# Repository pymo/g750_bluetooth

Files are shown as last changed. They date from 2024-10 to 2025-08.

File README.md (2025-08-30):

# HP Compaq IPAQ G750 Keyboard Bluetooth Adapter

Demo of G750 keyboard

This project makes a Bluetooth adapter for the G750 foldable keyboard. This keyboard was meant to use with vintage PDAs (Windows CE, Palm, Clie etc.). It was sold under various brands (HP, Compaq, Dell, Treo etc.) and has multiple model numbers (G750, G7L0, G7L1, etc.). But as long as they have the same look, this adapter should work for them.

The G750 keyboard uses an distinctive folding mechanism that slides out to both sides, while the middle piece raises up to the same level. A connector is prop’ed up to provide connectivity to the PDA. This project achieved Bluetooth functionality by replacing that connector module with a custom designed Bluetooth module. The Bluetooth module supports BLE 5.3, can pair up to 4 hosts simultaneously, and supports wired USB connection.

Note that there are two variants of the electrical characteristics: G750 uses inverted-TTL for its RX line, while G7L0, G7L1 uses TTL level. Some keyboards also have one or two extra keys depending on the layout and the PDA's OS. See the [protocol analysis and keycodes](g750_protocol.md) for details. Therefore, the hardware wiring and the firmware are slightly different for different models.

There is one exception: G700 for Toshiba, it uses USB protocol instead of serial, so it can not be supported. (There is also a G700 for Palm and Sony Clie, maybe that can be supported, but I haven't tested it yet.)

Support status
-----------

| Brand | Model | Supported | logic level |
| :---: | :---: | :---: | :---: |
| HP | G750 | Yes | inverted TTL |
| Compaq | 249711-001 | Yes | inverted TTL |
| ViewSonic | PPC-KYB-001 | Yes | inverted TTL |
| Dell | G7L0 or G7L1 | Yes | TTL |
| Treo | G740 | Yes | TTL |
| Belkin | G700 for Toshiba | No | USB protocol |
| Belkin | G700 for Palm/Clie | ? | unknown protocol, 5 wires |

Where to buy
-----------

The keyboard itself can be found on eBay for around $20. You can search using the keywords "G750", "249711-001", "G7L0" or "G7L1" + "Keyboard". G740 for Treo has a weird key layout, but if you are willing to swap keycaps, it's also a viable choice.

I have some modded keyboards for sale on [https://www.ebay.com/itm/226948142510](eBay).

If you want the adapter, I've made some for sale at Tindie. [https://www.tindie.com/products/36279/](https://www.tindie.com/products/36279/)

G750 protocol analysis
-----------

[Protocol analysis and keycodes](g750_protocol.md)

Instruction to make the adapter
-----------

[Tutorial for making the adapter](how_to_make.md)

Instruction to install the adapter
-----------

[Tutorial for installing the adapter into the keyboard](install.md)

PCB design and firmware
-----------
These are in a [separate repo](https://github.com/pymo/wch_micro_kbd/), the PCB design is shared with the Palm Portable Keyboard Bluetooth mod. The PCB uses a WCH CH582F chip, a RISC-V based Bluetooth controller. It is low cost, power efficient and easy enough to use, which is why I chose it.

Spacebar Issue Fix
-----------
It is a known issue that these keyboard's spacebar can't reliably register. But [there is a simple fix for that](spacebar_fix.md).

Demo on Youtube
-----------

G750 Keyboard demo (https://www.youtube.com/watch?v=a8__Df5YKs4 "Converting the G750 folding keyboard into Bluetooth")

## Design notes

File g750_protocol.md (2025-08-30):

# G750 protocol analysis

The G750 keyboard and its variants use a three-wire serial protocol. After disassembling the connector module, you can see a JST 3-pin, 1.25mm pitch male header. The 3 wires are:

- Ground

- RXD (Serial data)
  - For G750, the voltage is RS232 level (or more precisely, invert-TTL level, where 0V is 1 and 3.3V is 0)
  - For G740, G7L0 and G7L1, the voltage is TTL level (0V is 0 and 3.3V is 1)

- VCC, I tested with 3.3v and it works.

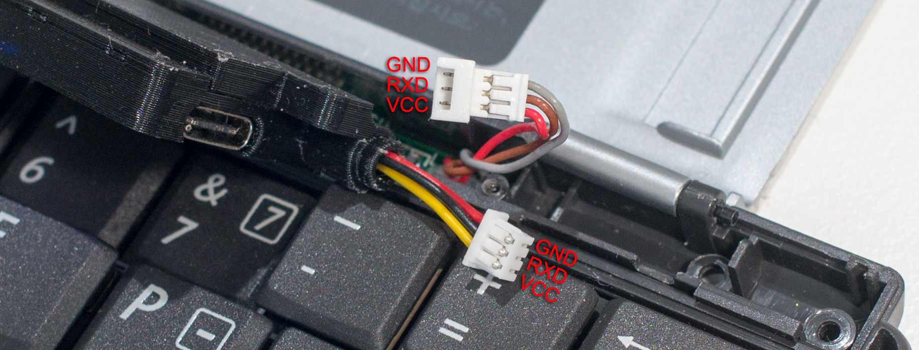
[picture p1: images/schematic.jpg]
Schematic


After the keyboard is supplied with VCC, when a key is pressed or released, it sends a 2-byte key-code over the serial wire. The baud rate is 4800n1. Let’s denote the two bytes as Byte1 and Byte2:

 - The most significant bit of Byte1 denotes the state of the key: 0 is pressed, 1 is released

 - The remaining 7-bit of Byte1 is the scancode, see the following table for the mapping

 - Byte2 is the inversion of Byte1’s 7-bit scancode. i.e. Byte1 & 0b01111111 == ~Byte2. I think it is for error detection. In practice we can ignore this byte and only look at the scancode in Byte1.

Scancode table
----------

G750 with US layout:

| Scan code | HID code | Scan code | HID code | Scan code | HID code | Scan code | HID code |
| :---: | :---: | :---: | :---: | :---: | :---: | :---: | :---: |
| 0x02 | HID_KEY_FN | 0x28 | HID_KEY_ARROW_UP | 0x43 | HID_KEY_I | 0x60 | HID_KEY_ARROW_DOWN |
| 0x07 | HID_KEY_GUI_LEFT | 0x2A | HID_KEY_V | 0x44 | HID_KEY_O | 0x66 | HID_KEY_DELETE |
| 0x0D | HID_KEY_TAB | 0x2B | HID_KEY_F | 0x45 | HID_KEY_0 | 0x70 | "Today" key |
| 0x0E | HID_KEY_GRAVE | 0x2C | HID_KEY_T | 0x46 | HID_KEY_9 | 0x71 | HID_KEY_BACKSPACE |
| 0x11 | HID_KEY_ALT_RIGHT | 0x2D | HID_KEY_R | 0x49 | HID_KEY_PERIOD | 0x73 | HID_KEY_CONTROL_RIGHT |
| 0x12 | HID_KEY_SHIFT_LEFT | 0x2E | HID_KEY_5 | 0x4A | HID_KEY_SLASH |  | |
| 0x14 | HID_KEY_CONTROL_LEFT | 0x2F | HID_KEY_ARROW_RIGHT | 0x4B | HID_KEY_L |  | | 
| 0x15 | HID_KEY_Q | 0x31 | HID_KEY_N | 0x4C | HID_KEY_SEMICOLON |  | |
| 0x16 | HID_KEY_1 | 0x32 | HID_KEY_B | 0x4D | HID_KEY_P |  | |
| 0x1A | HID_KEY_Z | 0x33 | HID_KEY_H | 0x4E | HID_KEY_MINUS |  | | 
| 0x1B | HID_KEY_S | 0x34 | HID_KEY_G | 0x52 | HID_KEY_APOSTROPHE |  | | 
| 0x1C | HID_KEY_A | 0x35 | HID_KEY_Y | 0x54 | HID_KEY_BRACKET_LEFT | | | 
| 0x1D | HID_KEY_W | 0x36 | HID_KEY_6 | 0x55 | HID_KEY_EQUAL |  | |
| 0x1E | HID_KEY_2 | 0x3A | HID_KEY_M | 0x58 | HID_KEY_CAPS_LOCK | | | 
| 0x21 | HID_KEY_C | 0x3B | HID_KEY_J | 0x59 | HID_KEY_SHIFT_RIGHT | | | 
| 0x22 | HID_KEY_X | 0x3C | HID_KEY_U | 0x5A | HID_KEY_RETURN |  | |
| 0x23 | HID_KEY_D | 0x3D | HID_KEY_7 | 0x5B | HID_KEY_BRACKET_RIGHT | | | 
| 0x24 | HID_KEY_E | 0x3E | HID_KEY_8 | 0x5C | HID_KEY_SPACE |  | |
| 0x25 | HID_KEY_4 | 0x41 | HID_KEY_COMMA | 0x5D | HID_KEY_BACKSLASH | | | 
| 0x26 | HID_KEY_3 | 0x42 | HID_KEY_K | 0x5E | HID_KEY_ARROW_LEFT | | | 

G750 with European (UK, ES etc.) layout, mostly the same with US but with the following difference:

| Scan code | HID code |
| :---: | :---: |
| 0x52 | (on the top of the up-arrow key), HID_KEY_EUROPE_1 |
| 0x74 | (to the right of the left-shift key), HID_KEY_EUROPE_2 |

G740 for Treo and G7L1 for Dell, the bottom row has one extra key to the left of the Space key:

| Scan code | G740 Key | G7L1 Key |
| :---: | :---: | :---: |
| 0x02 | Fn | Fn |
| 0x14 | Ctrl | Ctrl |
| 0x07 | opt | Windows |
| 0x70 | find |Today |
| 0x7a | Alt | Home |
| 0x5C | Space | Space |
| 0x11 | Home | alt |
| 0x73 | Menu | ctrl |
| 0x66 | Center | del |
| 0x5E | Left Arrow | Left Arrow |
| 0x60 | Right Arrow | Down Arrow |
| 0x2F | Down Arrow | Right Arrow |

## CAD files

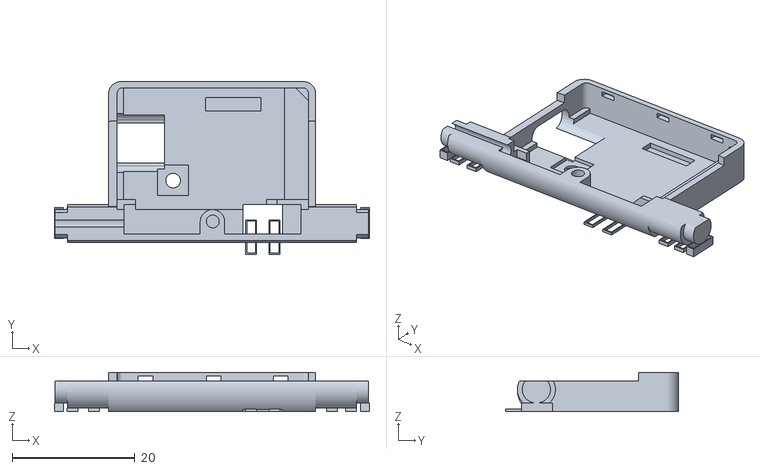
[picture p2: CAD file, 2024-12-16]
3d_print/base.stl
51.2 x 28.1 x 6.40

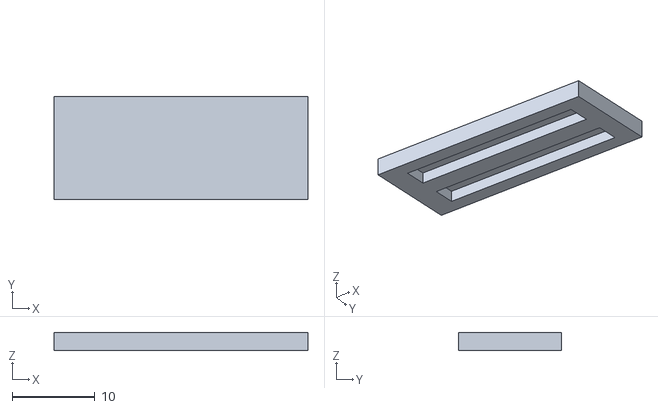
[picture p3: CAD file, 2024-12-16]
3d_print/support_for_cap.stl
30.7 x 12.4 x 2.20

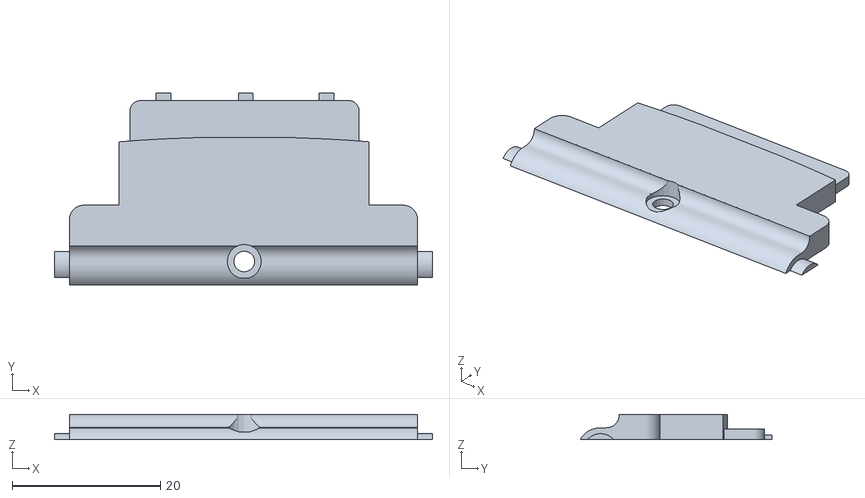
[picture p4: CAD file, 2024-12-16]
3d_print/cap.stl
51.0 x 25.8 x 3.40

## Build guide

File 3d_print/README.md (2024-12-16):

# Tips for how to print cap

First print the support for cap. Put some Kapton Tape over the flat side of the support. Slice the cap in your slicer software, put a pause point before the bridge layer, then print.

During the print, when paused, put the support with the Kapton Tape side up, then continue the print, so you can get a cap with smooth under surface.

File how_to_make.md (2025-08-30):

# How to make the G750 adapter (CH582F based)

Note: If you don't want to start from scratch and make this adapter, you can just buy the adapter from [Tindie](https://www.tindie.com/products/36279/) and skip the making process.

Bill of Materials
----------
- [WCH Micro Kbd board](https://github.com/pymo/wch_micro_kbd/), you can buy it from my [Tindie store](https://www.tindie.com/products/35183/). You can also fabricate it yourself using the gerber file in [my other repo](https://github.com/pymo/wch_micro_kbd/tree/main/pcb/).
- 3-pin JST 1.25mm pitch connector with wires.
- Some thin, flexible wire for the switch connection. I use 30 AWG PVDF insulated single core wire.
- 401225 Li-Po battery 100mAh (4mm x 12mm x 25mm in dimensions).
- One travel limit switch, model No. [KFC-V-511](https://www.aliexpress.com/item/3256802435427161.html). Please use this exact model, because the enclosure is specifically designed around it.
- 3D printed enclosure (stl models are in the 3d_print/ folder).
- One M2 screw, 4mm long.
- Double-sided tape.

3D printed parts
----------------
See the stl files in 3d_print/ folder. It comes in 2 files: the upper cap, the main frame. The upper cap needs a support to print, see the README there. The main frame has some support already added, it can be printed directly. PLA filament is recommended, because it is more rigid.

I used TinkerCAD to create these models. If you are interested in modifying the 3D model, you can visit this link: https://www.tinkercad.com/things/e2wjntFVclj-g750-keyboard-adapter

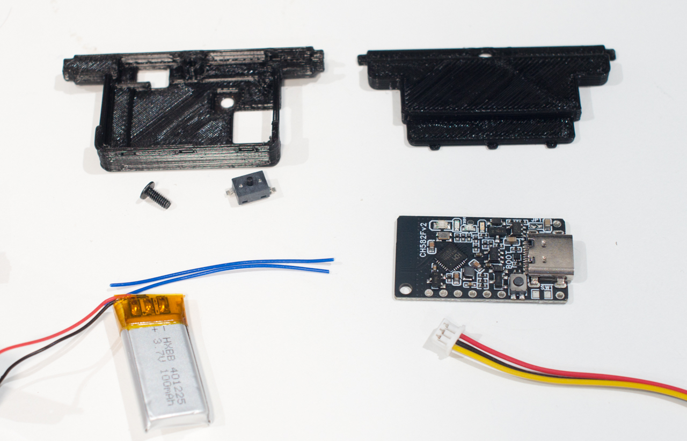
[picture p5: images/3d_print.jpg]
Printed parts before assembly


How to make the Bluetooth assembly
-------------------

Solder two 4 cm length thin wires to the SW1 pads, and the other ends of wires to the travel limit switch.

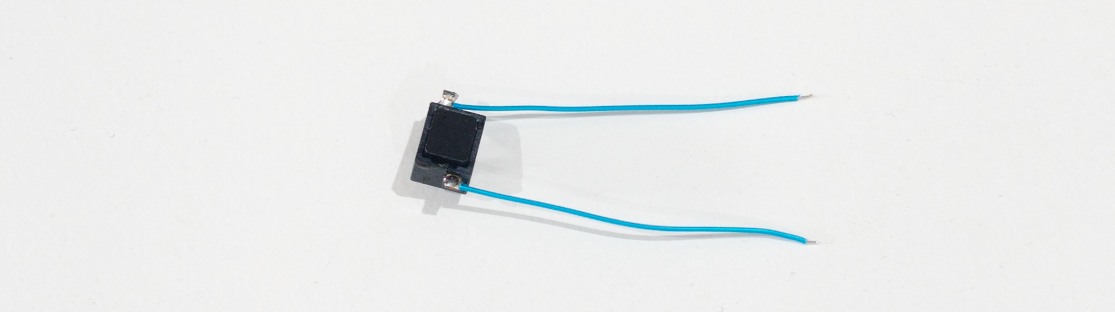
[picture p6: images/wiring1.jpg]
wiring pic


Cut the JST wire into the following dimension, the length is different for G750 (inverted TTL level) and other variants (TTL level):

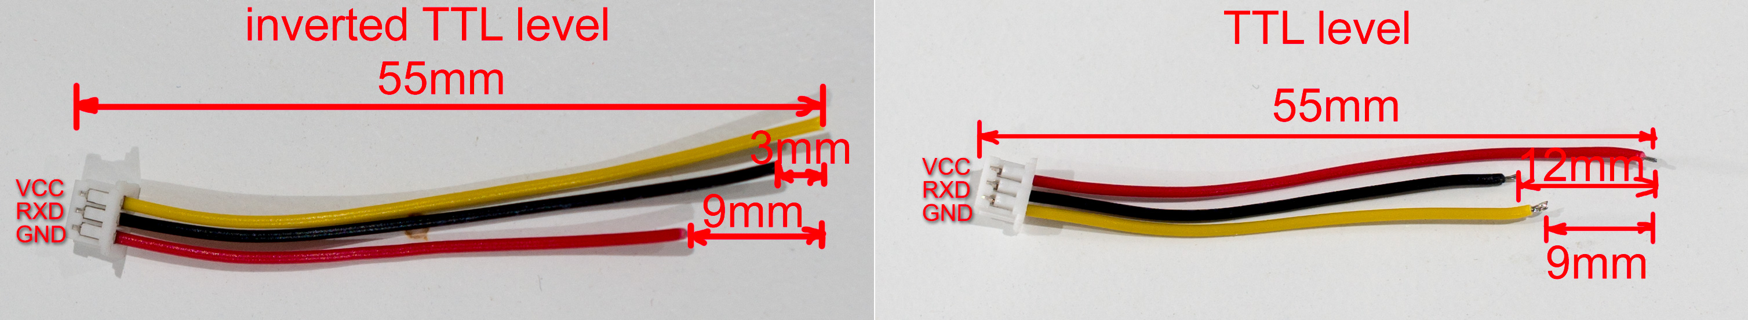
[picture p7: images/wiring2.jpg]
wiring pic


Then solder the JST wire to the PCB (the color of the wire may vary, what's important is the order of the wire at the connector):
 - For G750 (inverted TTL level), solder VCC to pad 1, RXD to pad 2, GND to pad 5
 - For other variants (TTL level), solder VCC to pad 1, RXD to pad 6, GND to pad 5.

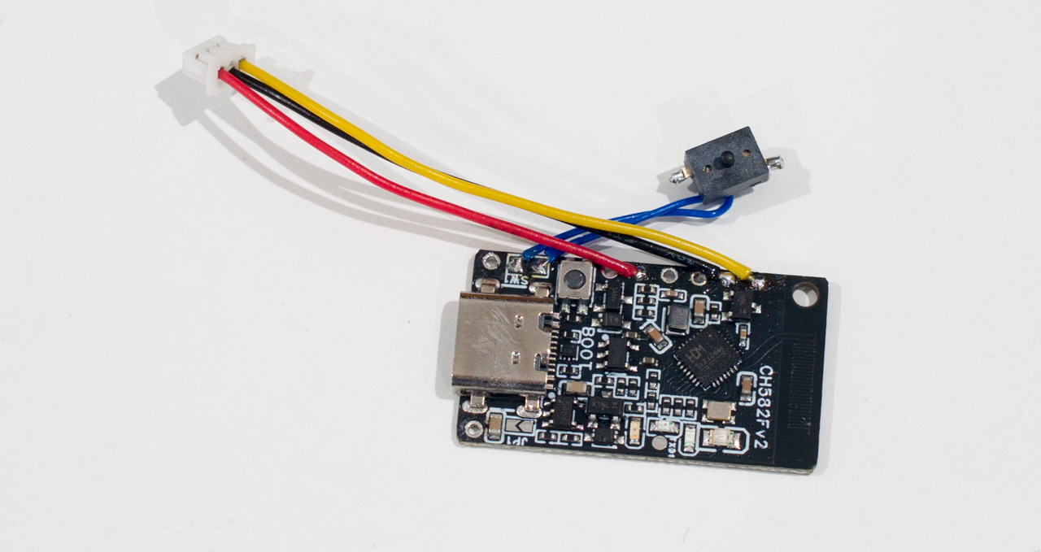
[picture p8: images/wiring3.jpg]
wiring pic


Solder the positive of the Li-Po battery to pad [BAT+], the negative to pad [BAT-].

Insert the PCB into the main frame like this, run the 3 wires in the tube.

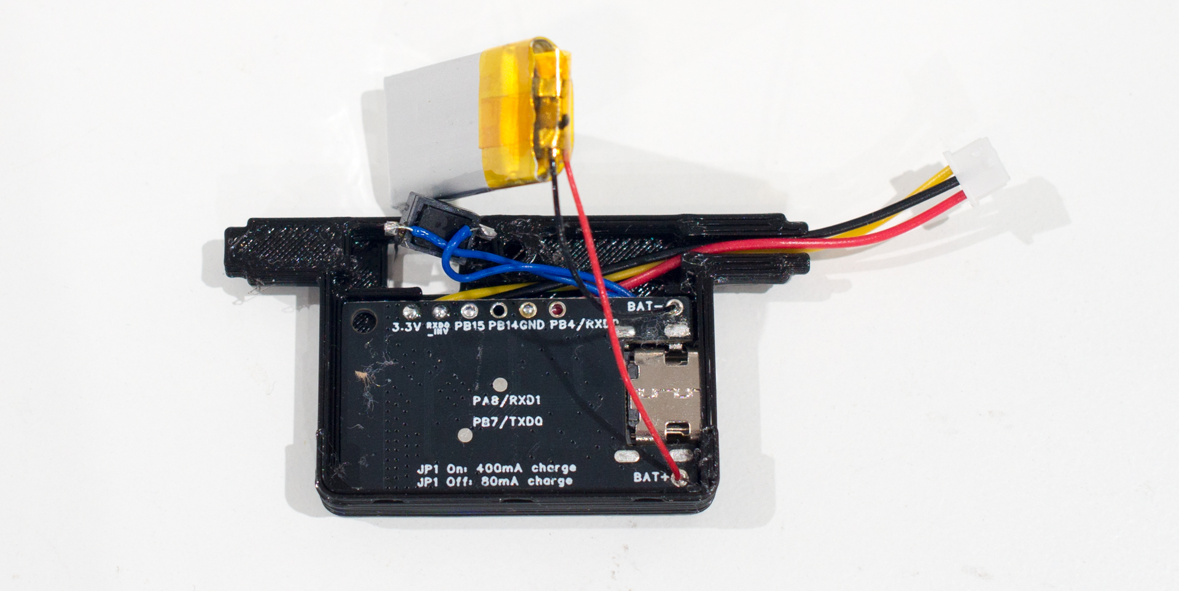
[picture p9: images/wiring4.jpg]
wiring pic


Put some super glue on the shorter sides of the switch, and install the switch in the main frame, glue it in-place.

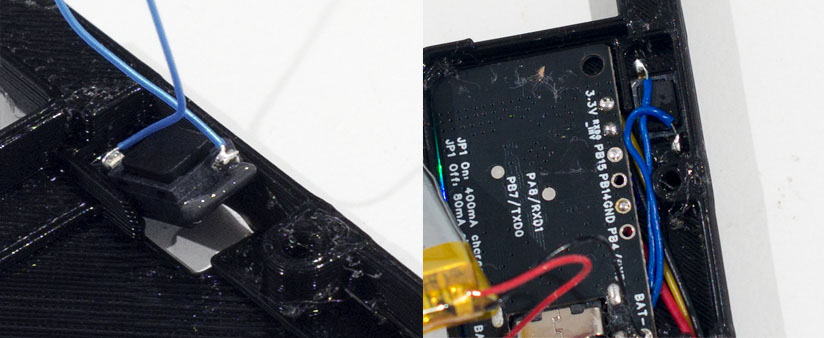
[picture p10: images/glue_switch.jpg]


Use double-sided tape to tape the battery at the following location. The upper edge of the battery should align with the upper edge of the PCB.

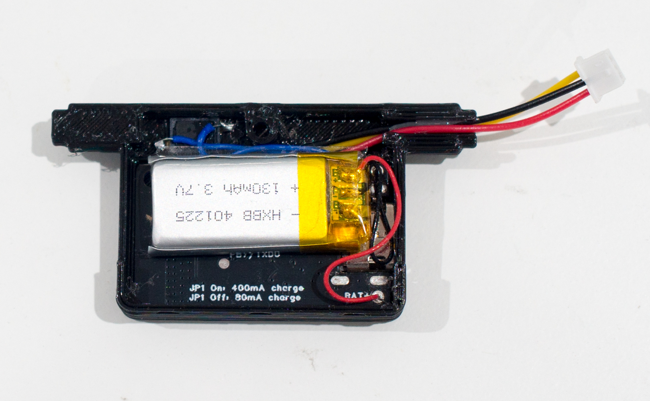
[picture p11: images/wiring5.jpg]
Glue the switch


Put the cap over the main frame. Put in the clips first, then screw in the M2 screw.

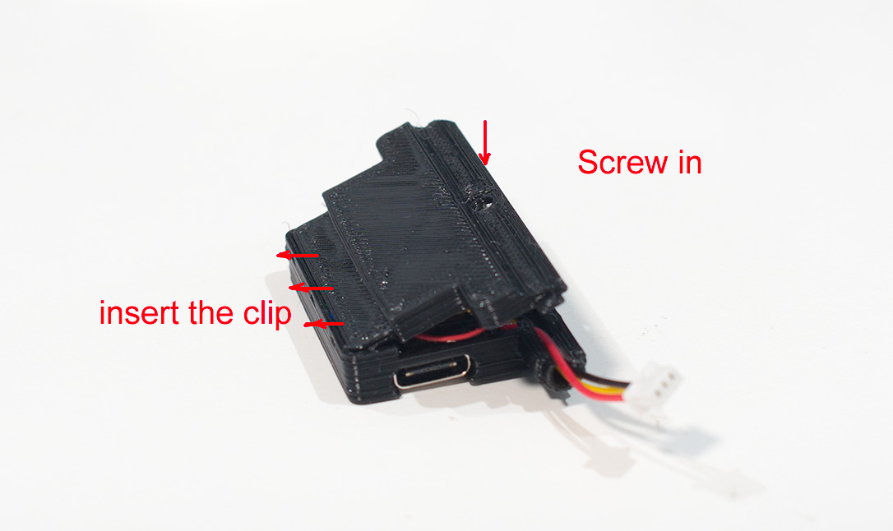
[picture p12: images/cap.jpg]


Programming
-----------
Follow [this tutorial](https://github.com/pymo/wch_micro_kbd/blob/main/doc/wch_isp_tool.md) to flash the firmware. The firmware can be downloaded from the release page of that Github. You need Windows PC to flash the firmware.

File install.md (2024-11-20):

# How to install the Bluetooth assembly to the keyboard

First of all, if you purchased the adapter from me, remove the protective cover for the micro switch. Check if the micro switch on the adapter has stuck at its OFF position during shipping. If it does, gently nudge the nib to let it pop out.
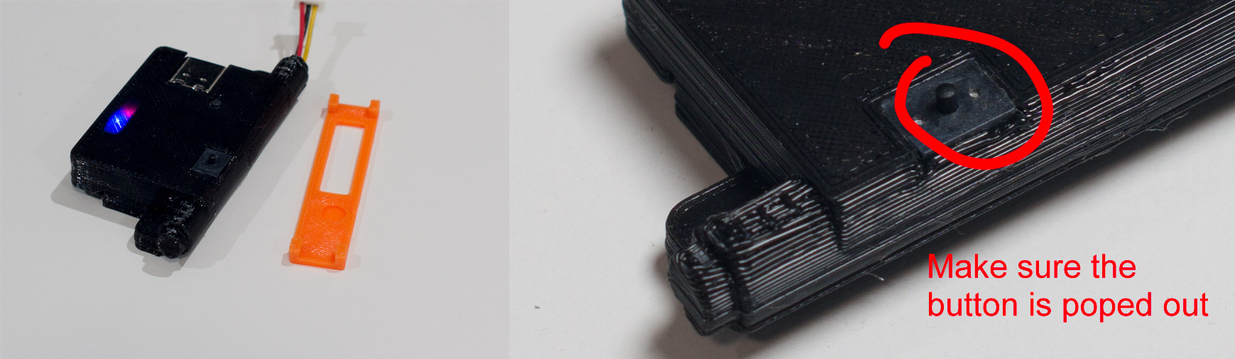
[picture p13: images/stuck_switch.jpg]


Unscrew the 3 screws at the back and 2 screws at the front of the keyboard.
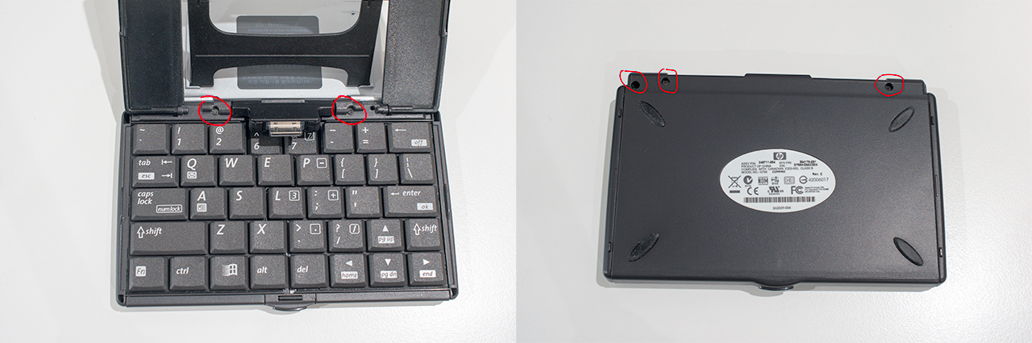
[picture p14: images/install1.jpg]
install pic


Remove the cover assembly.
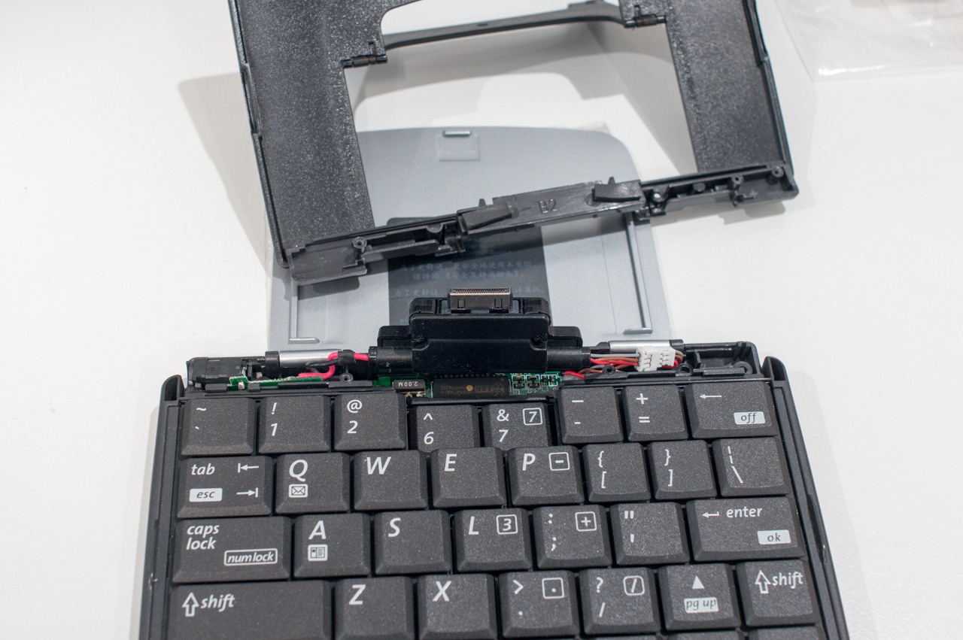
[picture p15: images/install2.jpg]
install pic


Remove the connector assembly from the cover assembly, unplug the 3-pin plug.
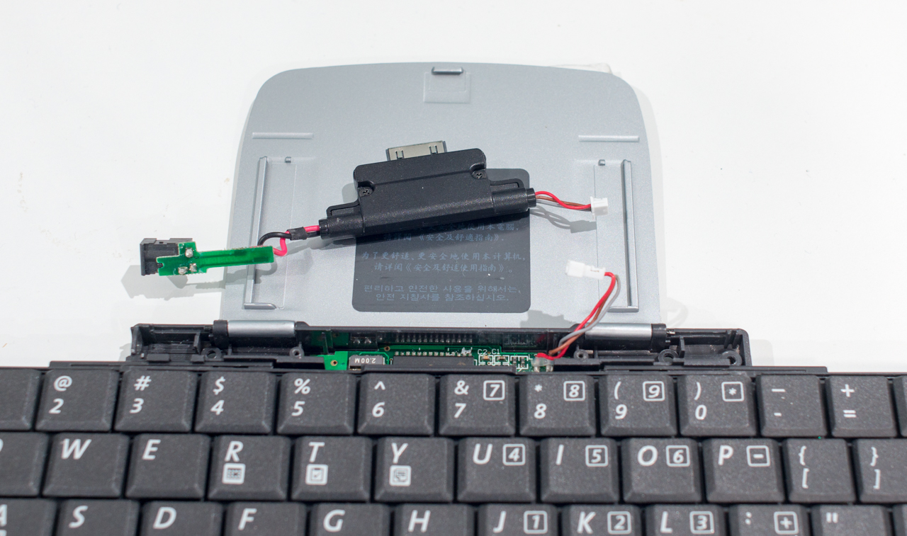
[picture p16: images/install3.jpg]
install pic


Put in the Bluetooth assembly into the cover assembly, plug-in the 3-pin plug, make sure all the pins are properly connected.
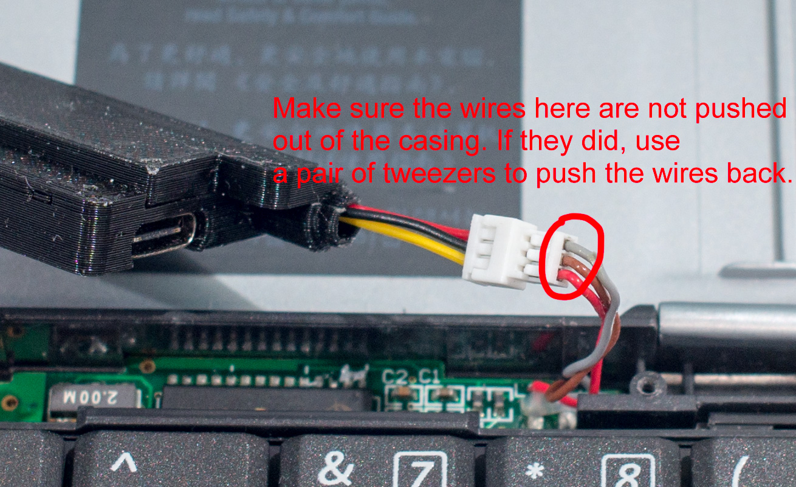
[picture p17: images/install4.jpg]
install pic


Tuck the connector in its compartment. Put back the cover assembly. Note that there is a center piece on the cover needs to go under the center keyboard part.
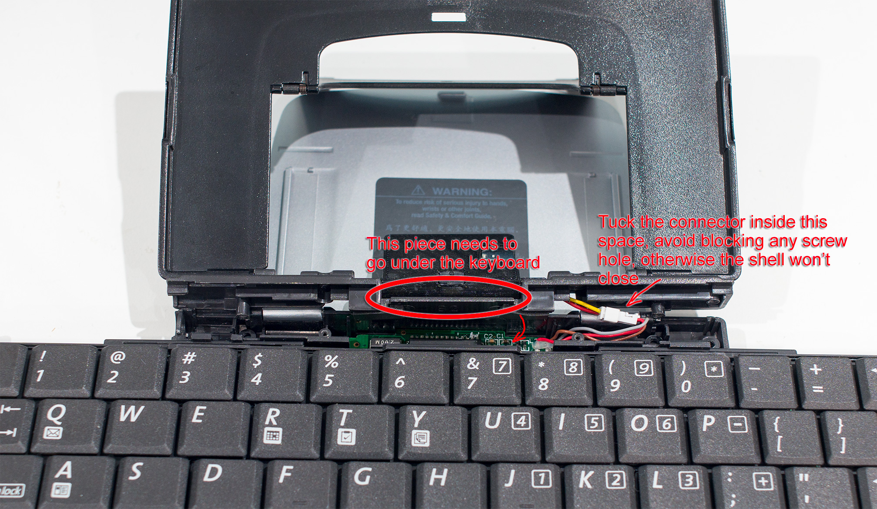
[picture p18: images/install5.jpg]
install pic


Screw the 5 screws.
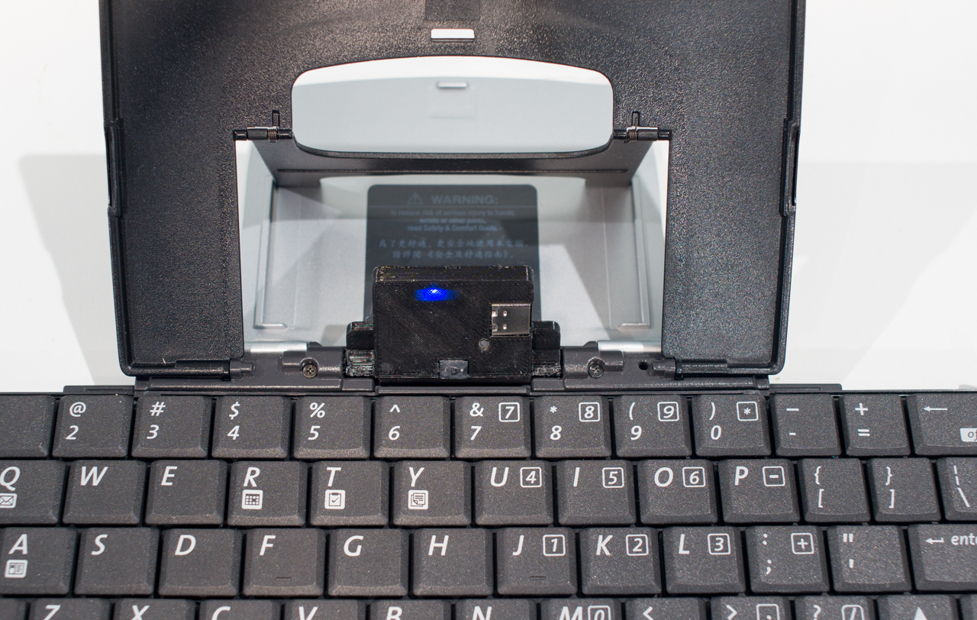
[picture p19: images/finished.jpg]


Safety warnings
---------------------
- As with any device using Li-Po battery, don't dismantle or damage the battery. Don't discharge the battery to a very low state. Please charge the battery as soon as you see the red LED blinks to ensure the longevity of the battery.

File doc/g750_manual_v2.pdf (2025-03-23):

# G750 Keyboard Bluetooth Adapter Manual

hardware rev. 2.0 2025-03-20 Dear friend,

Thank you for your interest in this project. Hope this little gadget can revive your G750 Keyboard and put it to good use! If you like this product, feel free to leave a review on the store page!

How to install:
- Please refer to the guide at https://github.com/pymo/g750_bluetooth/blob/main/install.md

Spacebar issue:
- It is a known issue that the keyboard's spacebar can't reliably register. But there is a simple fix for that: https://github.com/pymo/g750_bluetooth/blob/main/spacebar_fix.md

How to use after installation:
- If the adapter's battery is depleted, charge it up using a USB type-C cable (not included)
- Unfold the keyboard, the adapter automatically powers on. Search it on your phone or PC’s Bluetooth settings, it shows up as “PDA Keyboard 1”. Pair it and it will work.
- The adapter supports pairing up to 4 Bluetooth hosts simultaneously, and supports wired USB connection, too.
- Press Fn+A, S, D or F to switch between Bluetooth hosts 1~4, the Bluetooth name is "PDA Keyboard 1/2/3/4", respectively.
- Long press Fn+A, S, D or F for 1 second to force that "channel" into pairing mode again.
- Press Fn+U to switch to USB mode (it does not automatically switch to USB mode when USB cable is plugged in, the user has to manually switch it)
- To factory reset the adapter, use a pin or a paper clip to press and hold the small button on the adapter for 3 seconds. Do this if you have pairing issues. You also need to "forget" the keyboard in the host's settings before pairing again.

LED Functionality:
- Yellow LED: charging indicator
- On: charging.
- Off: charge complete.
- Blue LED: Bluetooth indicator
- Blue and Red alternately blink: Bluetooth pairing mode.
- Fast blink: reconnecting to the last paired host.
- Slow blink 1/2/3/4 times: Paired to the host 1/2/3/4, normal usage. The blink will stop after 30 seconds to avoid distraction.
- Constant on: USB mode. The LED will turn off after 30 seconds to avoid distraction.
- Off: the keyboard is in sleep, or it has been more than 30 seconds since the last mode switch.
- Green LED: Caps Lock indicator

- On: Caps Lock on.
- Off: Caps Lock off.
- Red LED: battery indicator
- blink once: battery is below 20%.
- blink twice: battery is below 15%.
- blink three times: battery is below 10%.

Keyboard Shortcuts:
Keystroke Combination | Function
Fn + A, S, D, F | Bluetooth host switch.
Fn + A, S, D, F (long press 1 second) | Enter pairing mode for this host.
Fn + U | USB mode
Fn + 1, 2, 3, ... -, = | F1, F2, F3, ... F11, F12
| Space (the default firmware assumes the and the alt keycaps are already swapped)
Fn + tab | Esc
Fn + del | Insert
Fn + | iOS Home
Fn + [ or ] | Brightness Down / Up
Fn + < or > | Volumn Down / Up
Fn + Space | Play / Pause
Fn + Q | Email
Fn + R | Calculator
Fn + P | PrintScreen

Self link:
This manual can be downloaded from https://github.com/pymo/g750_bluetooth/blob/main/doc/g750_manual_v2.pdf

Safety Warnings:
This device contains a Lithium-Polymer battery.
- Please do not crush, disassemble or puncture the device; There is a risk of fire by doing so.
- Please recharge as soon as the Red LED starts blinking, to maintain the longevity of the battery.
- If this device is not used for a long time, please charge it at least every 3 months.

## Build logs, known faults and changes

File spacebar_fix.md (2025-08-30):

# How to fix the reliablity of the spacebar for G750

The spacebar of the G750 (and similar variants) has the issue of not reliably register, this is due to the spacebar balancing mechanism does not provide enough pressing force to the membrane. We can fix that by adding some paddings to the back of the keycap.

1. Carefully remove the spacebar keycap. The technique is demonstrated in the [G750 Youtube video](https://www.youtube.com/watch?v=a8__Df5YKs4), you just need to do it to the two scissor structures for the spacebar.
2. Find a piece of about 0.8mm thick plastic card (e.g. a used credit card), cut it to 5x5 mm size.
3. Use some double-sided tape or super glue, to glue it to the back of the spacebar keycap, then snap the keycap back.

Now the spacebar should have better actuation reliability.

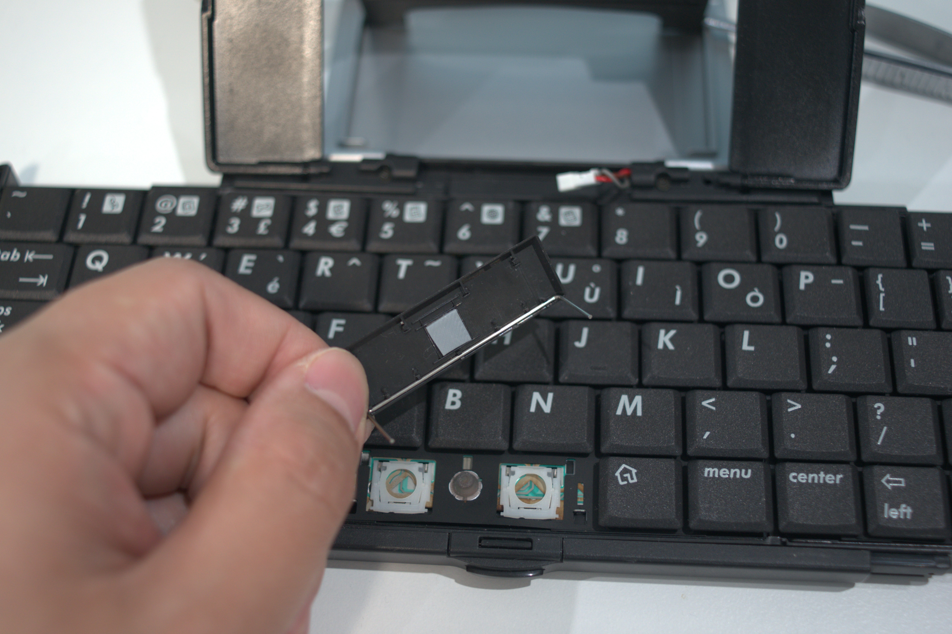
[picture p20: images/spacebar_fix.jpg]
spacebar pic


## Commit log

2024-12-16 Adds 3d print files
    [base.stl, cap.stl, support_for_cap.stl]
2025-02-03 change stuck switch photo
